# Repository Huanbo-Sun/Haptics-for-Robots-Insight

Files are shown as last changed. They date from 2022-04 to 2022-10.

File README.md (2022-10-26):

# Insight: A Haptic Sensor Powered by Vision and Machine Learning
<p align="right">
  *This is the only official content release regarding the design of Insight.*
</p>

This project shows the principle desing of [Insight](https://www.youtube.com/watch?v=lTAJwcZopAA&t=3s). It is a soft thumb-sized haptic sensor that can enbable robots feel directional force distributions all over a 3D conical surface.

The paper is titled "[A soft thumb-sized vision-based sensor with accurate all-round force perception](https://rdcu.be/cHCl9)", published at [*Nature Machine Intelligence*, 2022](https://rdcu.be/cHCl9). 

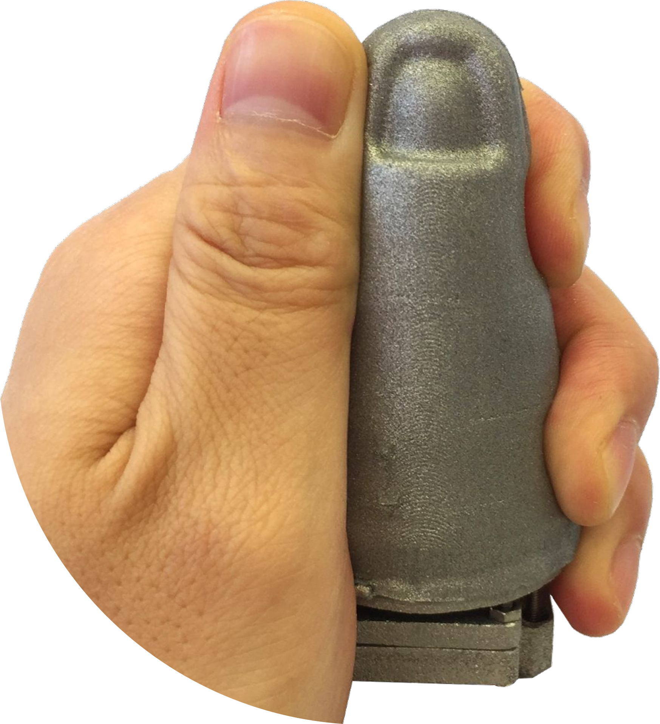
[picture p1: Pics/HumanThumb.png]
<p align="center">
  
This work was done by Huanbo Sun, Katherine J. Kuchenbecker, Georg Martius at the Max Planck Institute for Intelligent Systems.
  
If you make used of our work, please use the citation information [below](#Citation).
  
# Abstract
Vision-based haptic sensors have emerged as a promising approach to robotic touch due to affordable high-resolution cameras and successful computer vision techniques; however, their physical design and the information they provide do not yet meet the requirements of real applications. We present a robust, soft, low-cost, vision-based, thumb-sized three-dimensional haptic sensor named Insight, which continually provides a directional force-distribution map over its entire conical sensing surface. Constructed around an internal monocular camera, the sensor has only a single layer of elastomer over-moulded on a stiff frame to guarantee sensitivity, robustness and soft contact. Furthermore, Insight uniquely combines photometric stereo and structured light using a collimator to detect the three-dimensional deformation of its easily replaceable flexible outer shell. The force information is inferred by a deep neural network that maps images to the spatial distribution of three-dimensional contact force (normal and shear). Insight has an overall spatial resolution of 0.4 mm, a force magnitude accuracy of around 0.03 N and a force direction accuracy of around five degrees over a range of 0.03–2 N for numerous distinct contacts with varying contact area. The presented hardware and software design concepts can be transferred to a wide variety of robot parts.

# Working Mechanism
## Hardware Design
Insight is a vision-based haptic sensor that uses a camera and a structured lighting system to detect external contact happened on a soft hollow elastomer.
  
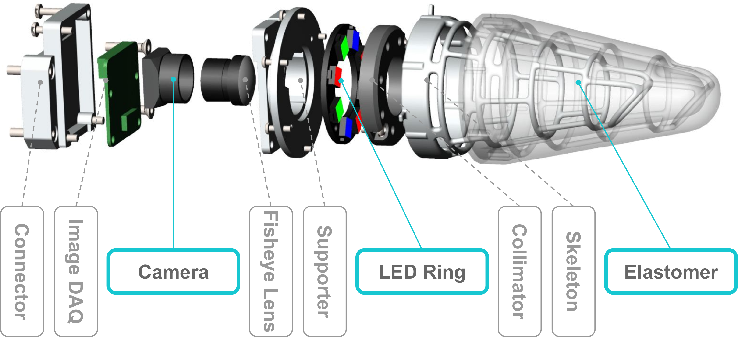
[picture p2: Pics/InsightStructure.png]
<p align="center">
  
## Software Design
Insight constantly records images from inside using a camera. Feeding these images and a reference image into a trained machine learning model makes it possible to estimate the force distribution all over a surface. Each pixel in the force prediction map has three values that indicate the force strength in three directions (x, y, and z). In a force visualization on the right, each point corresponding to each pixel in the force map shows the force distribution of the contact in both normal and shear directions.
  
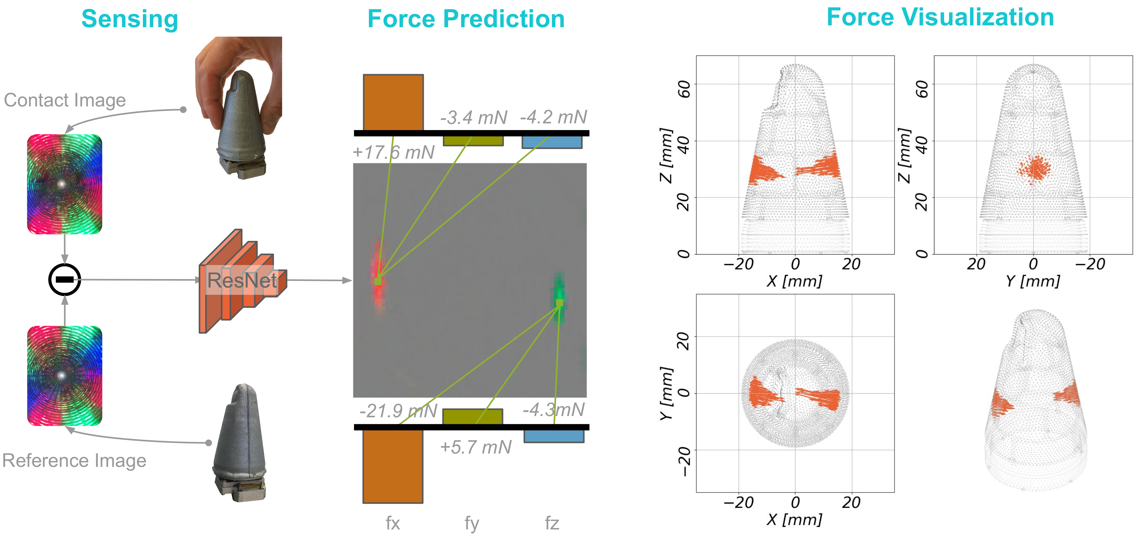
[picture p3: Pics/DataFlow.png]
  <p align="center">
    
# Key Components
Four key design components make Insight work properly: the mechanical design of its shell, the tailored imaging system inside, automatic data collection, and cutting-edge deep learning are used behind the scenes to create a cheap, robust, and high-fidelity device.
     
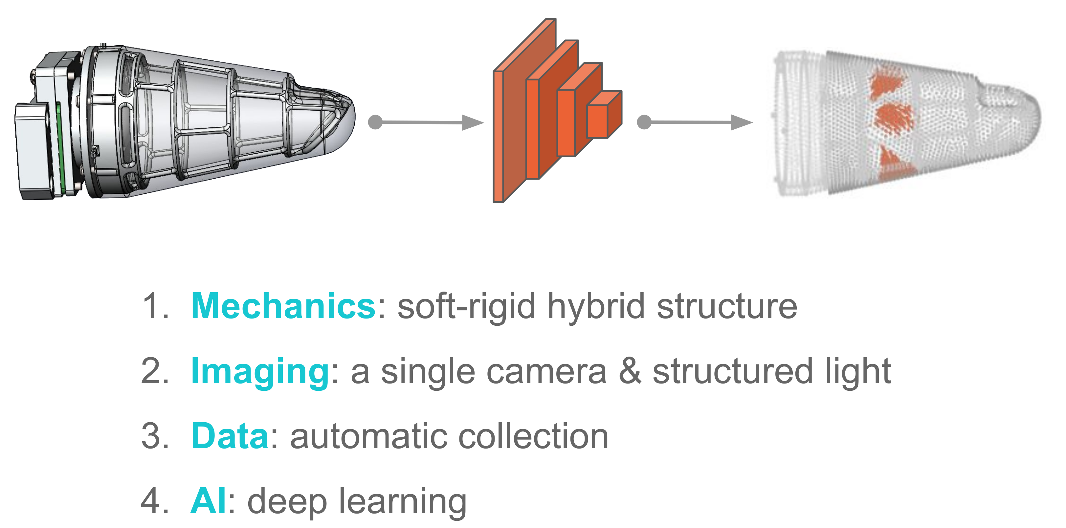
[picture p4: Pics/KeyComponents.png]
  <p align="center">
       
## Mechanics
Our hybrid structure of a soft elastomer shell enclosing a stiff metal skeleton ensures high sensitivity and robustness. The soft elastomer is for detecting light contact with high sensitivity. The metal skeleton is for holding the elastomer’s global shape and sustaining high-impact forces.

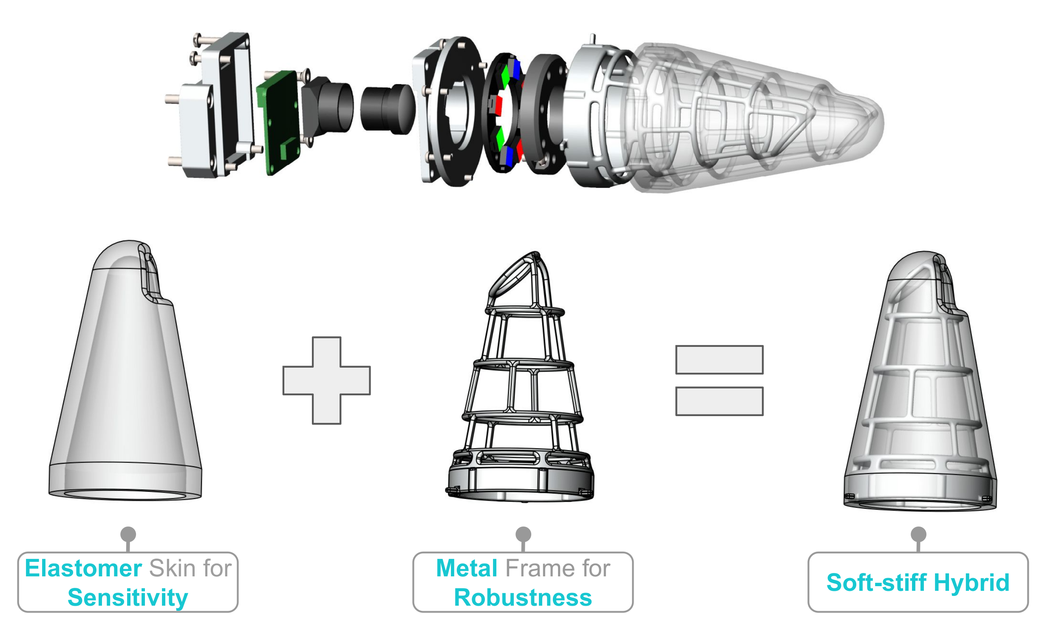
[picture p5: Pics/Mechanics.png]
  <p align="center">

### Elastomer
- 3D Printer: [Formlabs Form 3](https://formlabs.com/eu/3d-printers/form-3/)
- 3D Printing Material: [Tough Resin FLTOTL05](https://formlabs.com/store/tough-2000-resin/). *Note: The material is updated.*
- Mold Design: 
  - [Mold 1](Solidworks/Elastomer_Mold1_In_Fingerprint_NailFlat.SLDPRT)
  - [Mold 2](Solidworks/Elastomer_Mold2_Out1.SLDPRT)
  - [Mold 3](Solidworks/Elastomer_Mold2_Out2.SLDPRT)
- Elastomer Material:
  - [EcoFlex 00-30](https://www.smooth-on.com/products/ecoflex-00-30/)
  - [Aluminum Powder 65 Micrometer, 99% Pure](https://www.amazon.de/Aluminumpulver-Aluminium-Pulver-Alupulver-Zus%C3%A4tze/dp/B06WRTGP2Y)
  - [Aluminum Flake 75 Micrometer](https://www.metallpulver24.de/de/aluminiumpulver-flaky-silber.html)
- [Vacuum Chamber VP1100, 5 Pa](https://www.silikonfabrik.de/vakuumtechnik/komplettsysteme/vakuum-komplettsystem-vks27/vp1200-vakuumkammer-und-pumpe.html). *Note: The Pump is updated.*
       
### Metal Skeleton
- 3D Printer: [ExOne X1 25 Pro](https://www.exone.com/en-US/Resources/News/X1-25PRO)
- 3D Printing Material: [AlSi10Mg-0403 Alluminum Alloy](https://www.shapeways.com/materials/aluminum) *Note: The material is updated.*
- Geometry Design: [Skeleton](Solidworks/Skeleton.SLDPRT)
- Printing Service: [Shapeways](https://www.shapeways.com/)
       
### Connector and Supporter
- 3D Printer: [ExOne X1 25 Pro](https://www.exone.com/en-US/Resources/News/X1-25PRO)
- 3D Printing Material: [AlSi10Mg-0403 Alluminum Alloy](https://www.shapeways.com/materials/aluminum) *Note: The material is updated.*
- Geometry Design: 
  - [Connector](Solidworks/Connector.SLDPRT)
  - [Supportor](Solidworks/Supporter.SLDPRT)
- Printing Service: [Shapeways](https://www.shapeways.com/)
      
## Imaging System
We use a LED ring and a collimator to create structured light. The structured light forms a light cone inside the enclosed volume. Each voxel inside this volume has a specific color code with 3D information. External contact moves the elastomer from one color zone to another. Together with shading effects the camera can detect 3D deformations of the surface from a single 2D image. As shown on the right figure, mimicking human fingerprint, we also add ridges to the surface to help the system recognize the directions of the surface extension.

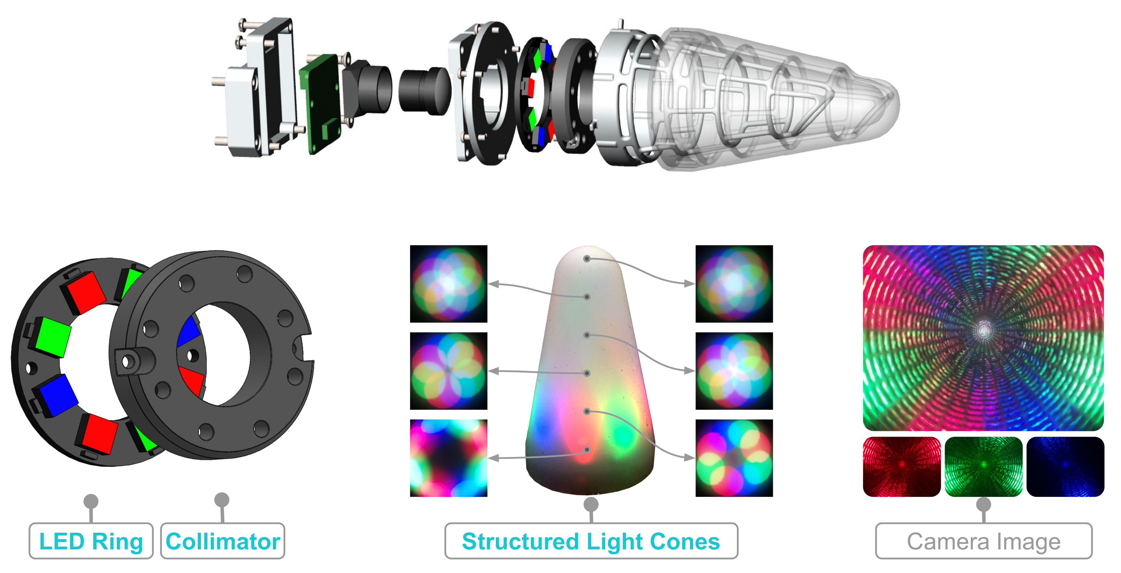
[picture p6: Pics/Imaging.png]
  <p align="center">
    
### Camera
- [Maker Hawk Raspberry Pi Camera Module 8 MP (Raspberry Pi camera V.2.0)](https://www.amazon.co.uk/MakerHawk-Raspberry-Compatible-Supporting-Resolution/dp/B07HL3Q58Z)

### LED Ring
- [Neopixel Ring with eight pieces of WS2812 5050](https://www.amazon.de/gp/product/B019ZL6724/ref=ppx_yo_dt_b_asin_title_o05_s00?ie=UTF8&psc=1)       

### Collimator
- 3D Printer: [Formlabs Form 3](https://formlabs.com/eu/3d-printers/form-3/)
- Material: [Standard Black](https://formlabs.com/de/shop/black-resin/)
- Geometry Design: [Collimator](Solidworks/Collimator.SLDPRT)

### DAQ
- [Raspberry Pi 4 Model B](https://www.raspberrypi.com/products/raspberry-pi-4-model-b/) 
- [Python Code Runs in Raspberry Pi](Code/Python-Rasberry.md)

## Testbed
We design a test bed to stimulate the sensor in a controlled way, with both normal and shear forces, over the entire 3D sensing surface.
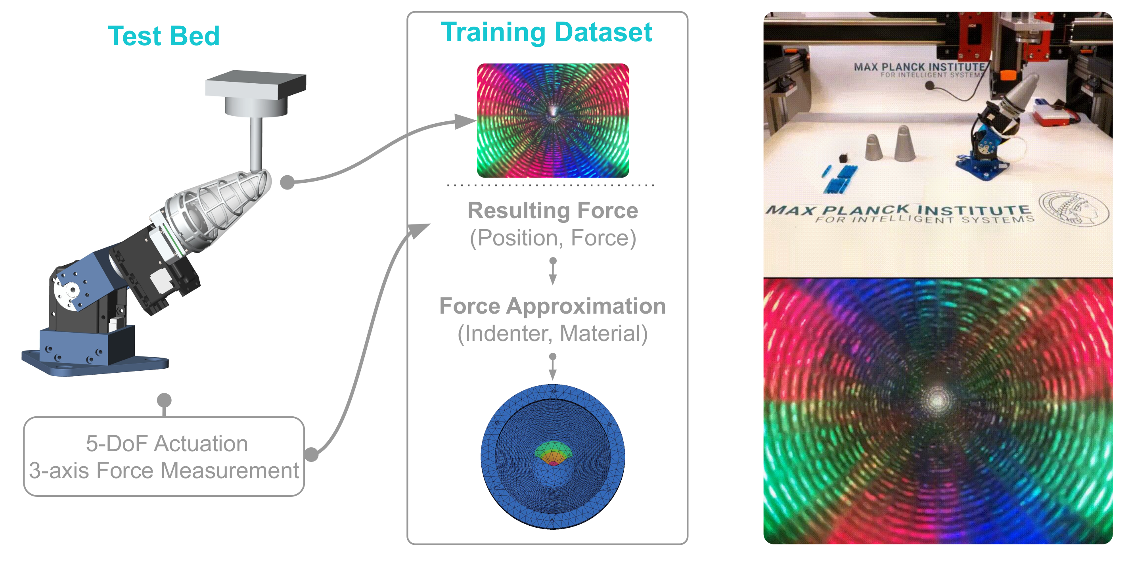
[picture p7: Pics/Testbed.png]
   <p align="center"> 

### Linear Guide for 3 DOF Translation
- [Linear Guide](https://www.barchmotion.com/)
   - [Linear Guide Geometry](Pics/BarchMotionGeometry.png)
   - [Linear Guide Order List](Pics/BarchMotionOrder.png)
- [Power Supplier](https://www.boomaudio.de/mean-well-rsp-320-36-netzteil)
   - [RSp-320-36](https://www.boomaudio.de/mean-well-rsp-320-36-netzteil)
- [Arduino for Testbed](https://store.arduino.cc/products/arduino-micro)
   - [Arduino Micro](https://store.arduino.cc/products/arduino-micro)
   - [Arduino Code](Code/Testbed-Arduino.md)

### Motors for 2 DOF Rotation
- [Dynamixel Mx28-AT](https://emanual.robotis.com/docs/en/dxl/mx/mx-28/)
- [Dynamixel Mx64-AT](https://emanual.robotis.com/docs/en/dxl/mx/mx-64/)
- [Connector Mx64-AT-Testbed-Base](Solidworks/Mx64-AT-Testbed-Base.SLDPRT)
- [Connector Mx28-AT-Mx64-AT](Solidworks/Mx28-AT-Mx64-AT.SLDPRT)

### Force/Torque Sensor
- [ATI-MINI 40](https://www.ati-ia.com/products/ft/ft_models.aspx?id=mini40)
- [DAQ](https://www.ni.com/de-de/support/model.usb-6210.html)
       
# Software
## [Data Collection](Code/00_Experiment.ipynb)
### Communication
### Coordinate Transfer
### Data Collection
## Data Processing
### Direct Single Contact Prediction
### Force Map Predcition
### Mapping/Visualization
       
# Citation
Please use the following citation if you make use of our work:
## BibTex
``` citation
@article{Insight,
  title = {A soft thumb-sized vision-based sensor with accurate all-round force perception},
  author = {Sun, Huanbo and Kuchenbecker, Katherine J. and Martius, Georg},
  journal = {Nature Machine Intelligence},
  volume = {4},
  organization = {Max Planck Institute for Intelligent Systems},
  month = feb,
  year = {2022},
  doi = {10.1038/s42256-021-00439-3},
  url = {https://rdcu.be/cHCl9},
  month_numeric = {2}
  } 
```
### RIS
``` citation
TY  - JOUR
AU  - Sun, Huanbo
AU  - Kuchenbecker, Katherine J.
AU  - Martius, Georg
PY  - 2022
DA  - 2022/02/01
TI  - A soft thumb-sized vision-based sensor with accurate all-round force perception
JO  - Nature Machine Intelligence
SP  - 135
EP  - 145
VL  - 4
IS  - 2
SN  - 2522-5839
UR  - https://doi.org/10.1038/s42256-021-00439-3
DO  - 10.1038/s42256-021-00439-3
ID  - Sun2022   
```

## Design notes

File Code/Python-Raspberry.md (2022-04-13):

```
# Packages
## Neopixel
import board
from fractions import Fraction
import neopixel
## Picamera
import picamera
from picamera import PiCamera, Color
from picamera.array import PiRGBArray
## Communication
import socket
import io
import struct
import pickle
## Processing
import numpy as np
import math
import time

# Camera
def imaging():
    camera = PiCamera(resolution=(1640,1232),framerate=40)
    camera.iso = 100
    time.sleep(2)
    camera.shutter_speed = camera.exposure_speed
    camera.exposure_mode = 'off'
    camera.awb_mode = 'off'
    camera.awb_gains = (Fraction(387,256), Fraction(477,256))
    return camera

# Light
def lightning():
    pixels_M = neopixel.NeoPixel(board.D18,8,auto_write=True)
    pr = 1.0#1.0
    pg = 1.0#0.9
    pb = 0.5
    b0 = int(255.0*pr)
    b1 = int(255.0*pg)
    b2 = int(255.0*pb)
    b3 = int(255.0*pr)
    b4 = int(255.0*pg)
    b5 = int(255.0*pr)
    b6 = int(255.0*pb)
    b7 = int(255.0*pg)
    pixels_M[0]=(b0,0,0)
    pixels_M[1]=(0,b1,0)
    pixels_M[2]=(0,0,b2)
    pixels_M[3]=(b3,0,0)
    pixels_M[4]=(0,b4,0)
    pixels_M[5]=(b5,0,0)
    pixels_M[6]=(0,0,b6)
    pixels_M[7]=(0,b7,0)
    pixels_M.write()
    time.sleep(0.025)

# Main
client_socket = socket.socket()
client_socket.connect(('--.--.--.--', ----))
a = client_socket.recv(256)
print(a)
connection = client_socket.makefile('wb')

lightning()
camera = imaging()
camera.start_preview()
time.sleep(0.1)

try:
    while True:
        a = client_socket.recv(256)
        stream = io.BytesIO()
        camera.capture(stream,'jpeg',use_video_port=True)
        connection.write(struct.pack('<L',stream.tell()))
        connection.flush()
        stream.seek(0)
        connection.write(stream.read())
        stream.seek(0)
        stream.truncate()
finally:
    time.sleep(1)
    connection.close()
    client_socket.close()
```

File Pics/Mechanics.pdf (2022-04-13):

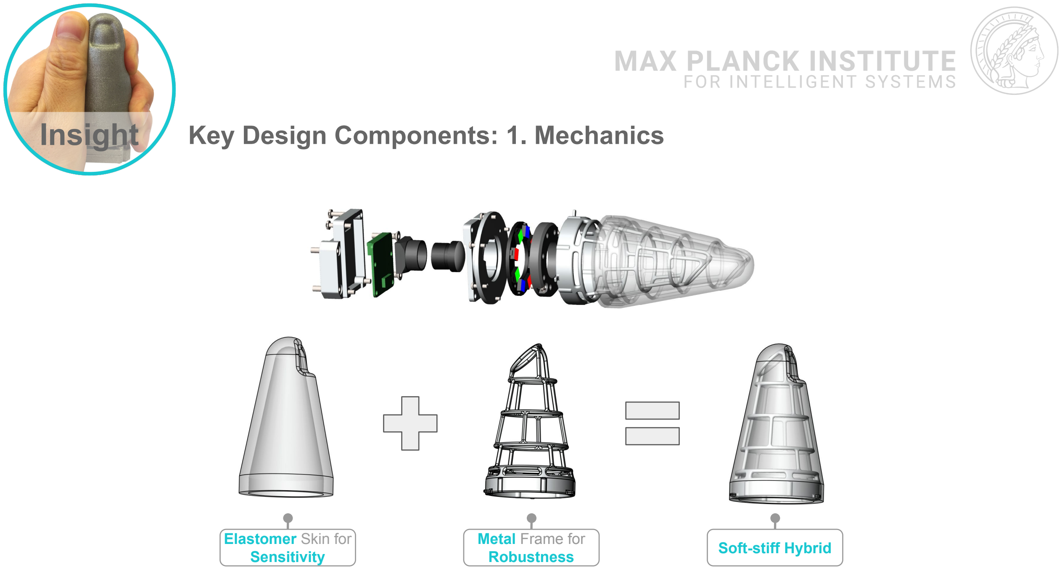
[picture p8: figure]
Key Design Components: 1. Mechanics; Elastomer Skin for Sensitivity; Metal Frame for; Robustness; Soft-stiff Hybrid

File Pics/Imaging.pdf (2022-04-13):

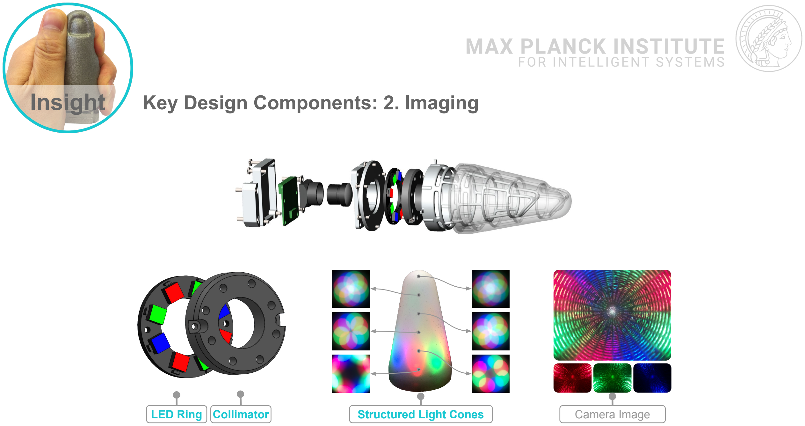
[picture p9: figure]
Key Design Components: 2. Imaging; LED Ring Collimator; Structured Light Cones; Camera Image

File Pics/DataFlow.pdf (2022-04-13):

Sensing | Force Prediction | Force Visualization

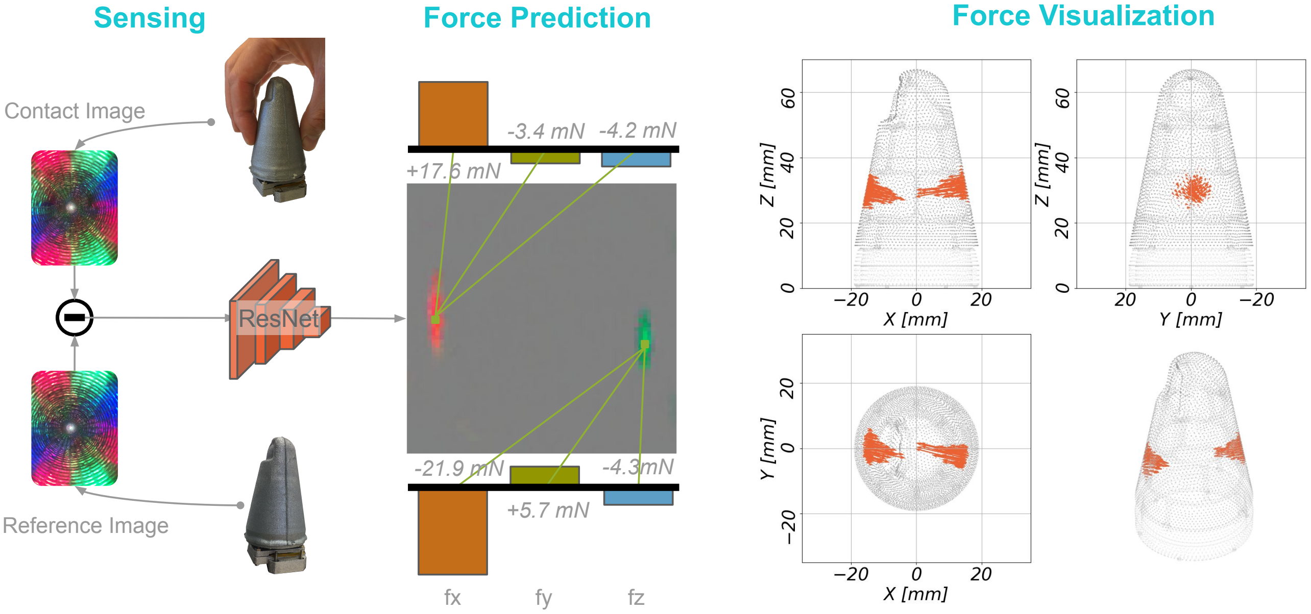
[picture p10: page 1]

+17.6 mN

-3.4 mN -4.2 mN

-21.9 mN

fx | fy | fz
| +5.7 mN | -4.3mN

Contact Image

Reference Image

ResNet

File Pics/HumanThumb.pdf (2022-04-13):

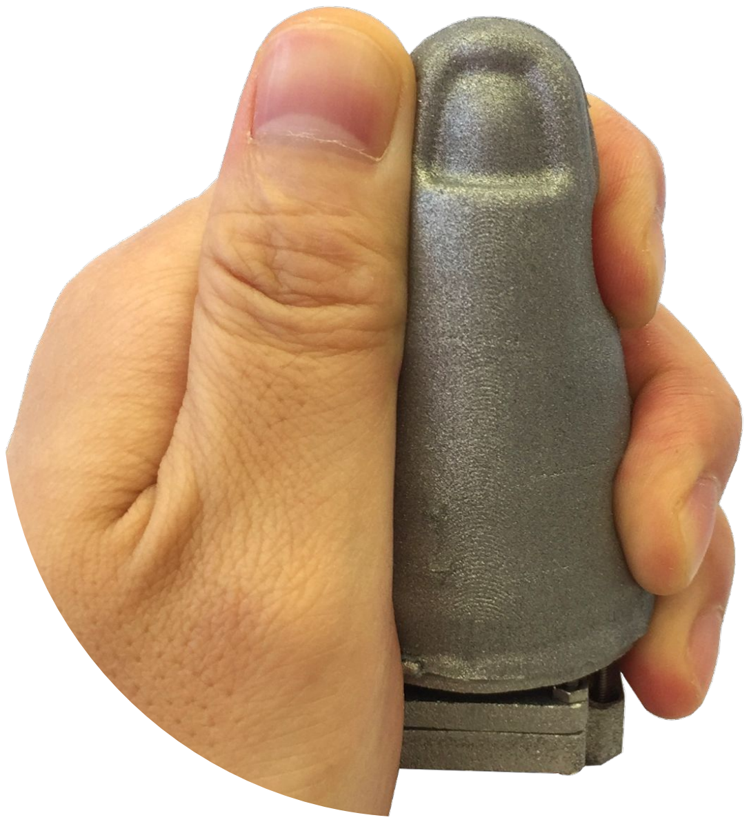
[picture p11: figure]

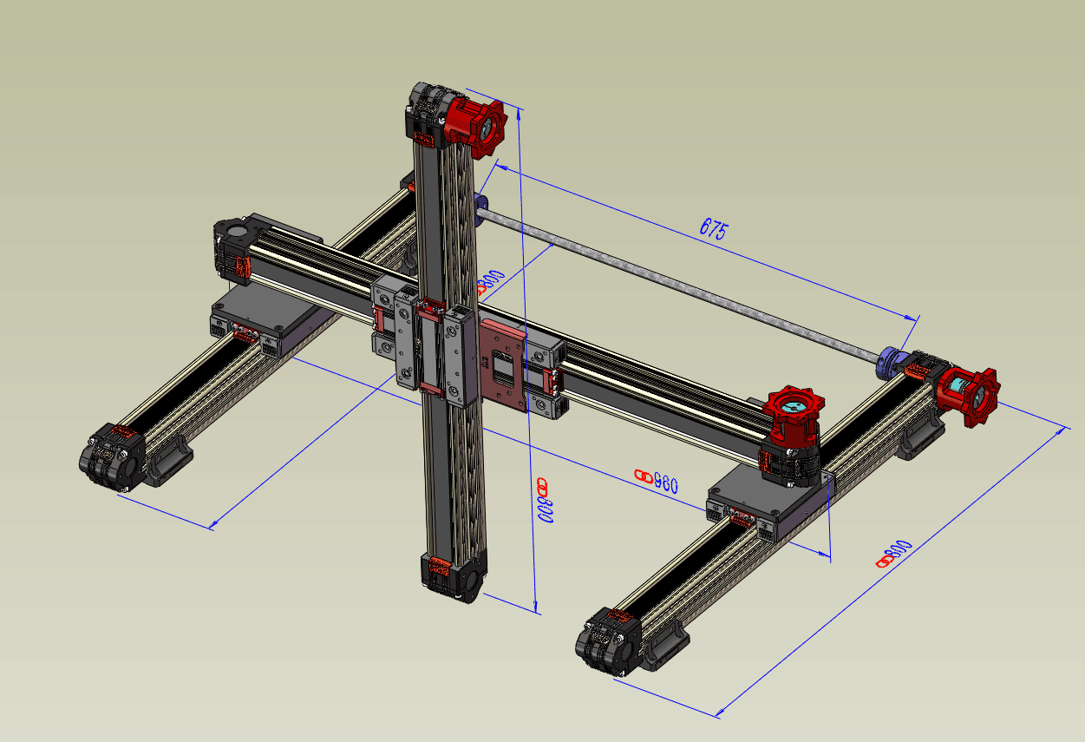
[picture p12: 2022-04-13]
Pics/BarchMotionGeometry.png

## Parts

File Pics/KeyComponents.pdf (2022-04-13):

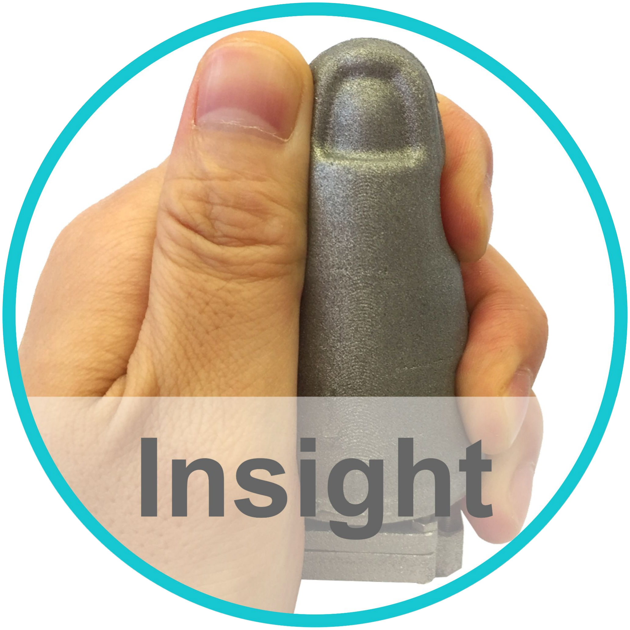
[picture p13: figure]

Key Design Components

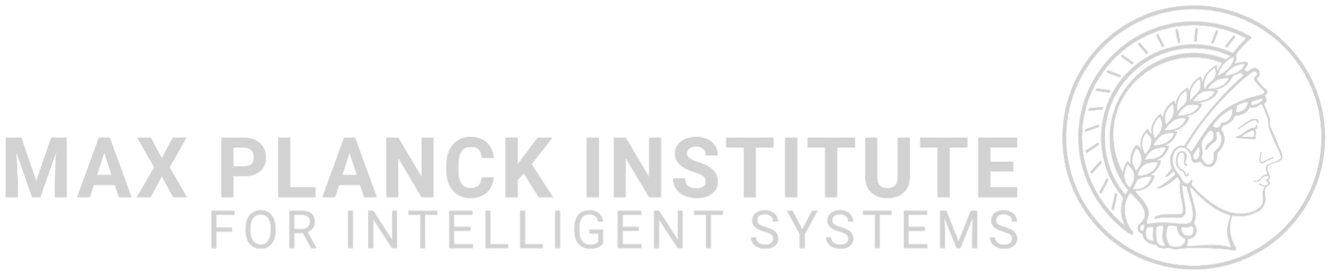
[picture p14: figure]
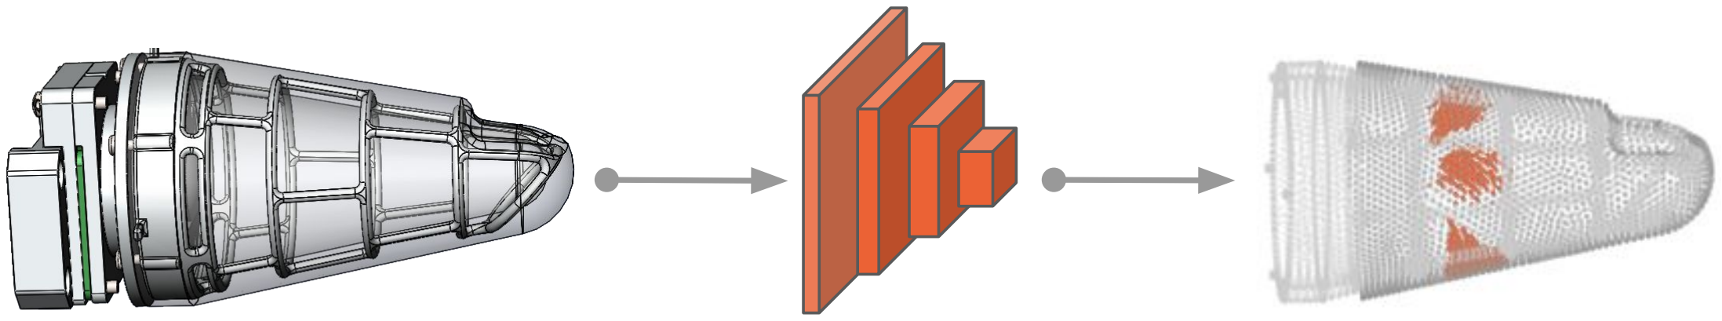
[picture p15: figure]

1. Mechanics: soft-rigid hybrid structure
2. Imaging: a single camera & structured light
3. Data: automatic collection
4. AI: deep learning

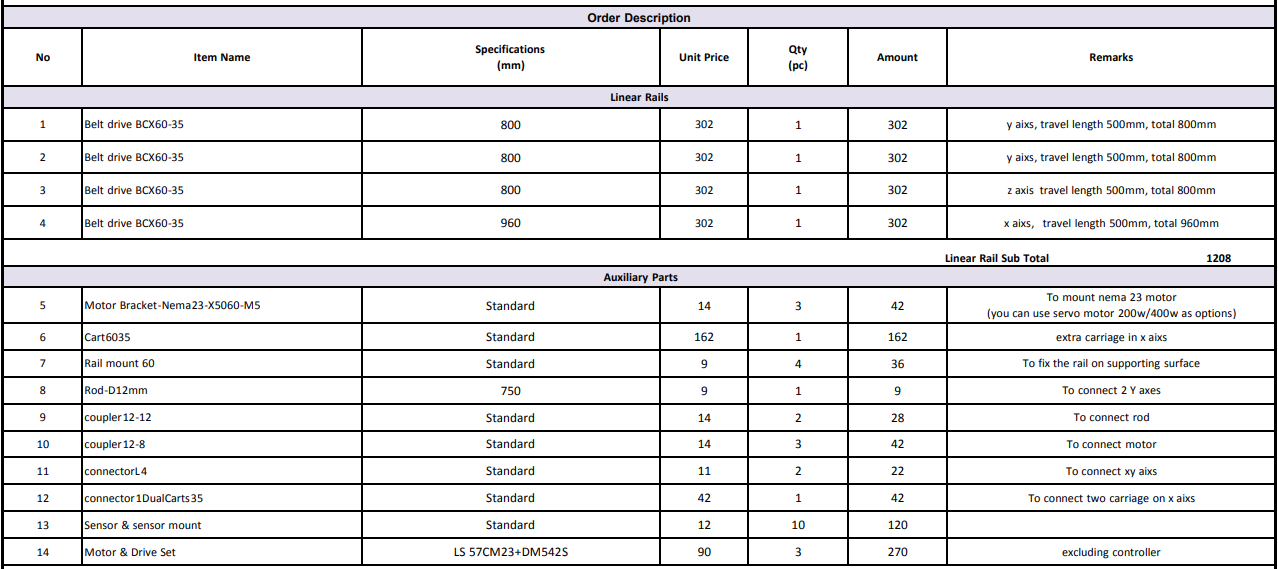
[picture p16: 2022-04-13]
Pics/BarchMotionOrder.png

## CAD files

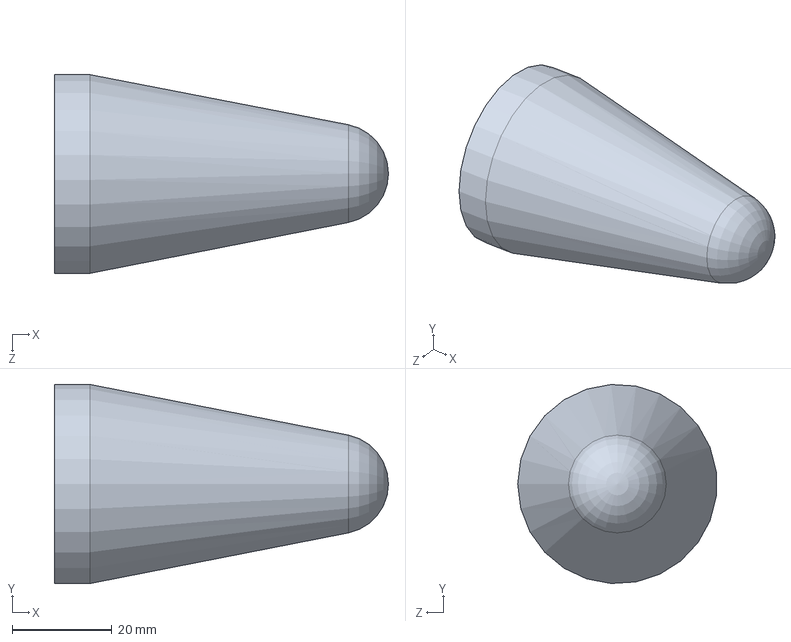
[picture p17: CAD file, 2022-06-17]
Solidworks/Smooth_Shell.SLDPRT
67.0 x 39.9 x 39.8 mm

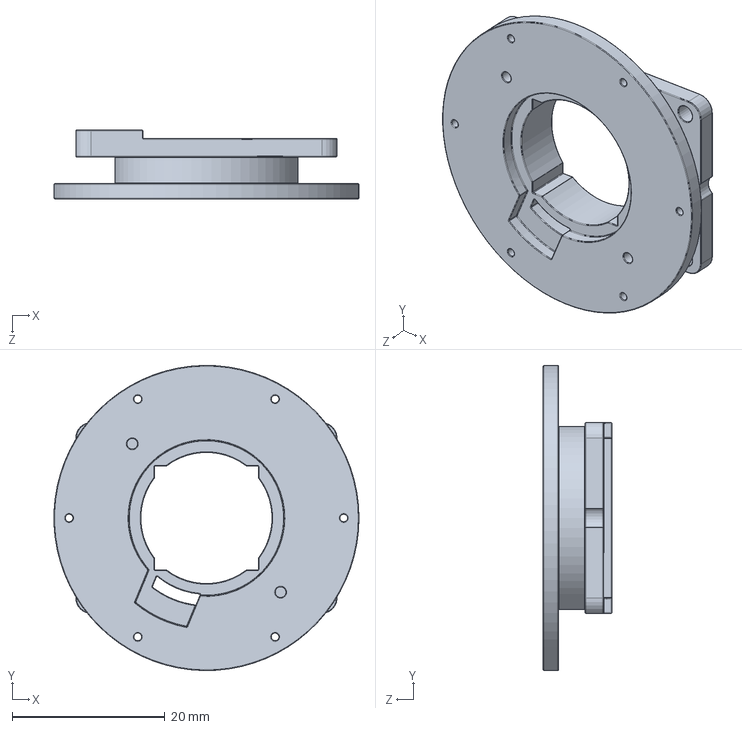
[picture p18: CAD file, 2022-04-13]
Solidworks/Supporter.SLDPRT
40.0 x 40.0 x 9.00 mm

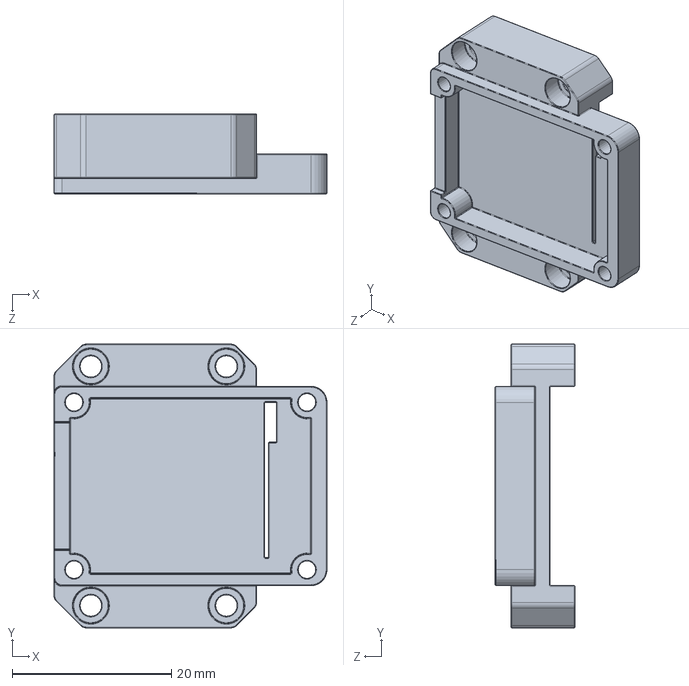
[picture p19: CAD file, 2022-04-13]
Solidworks/Connector.SLDPRT
34.2 x 35.6 x 10.0 mm

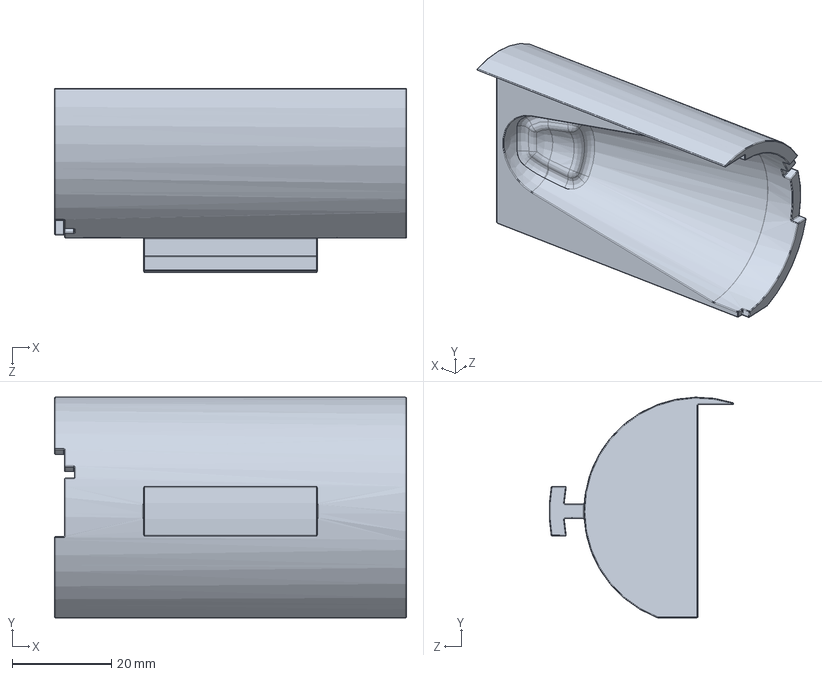
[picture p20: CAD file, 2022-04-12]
Solidworks/Elastomer_Mold2_Out1.SLDPRT
71.0 x 44.5 x 37.2 mm

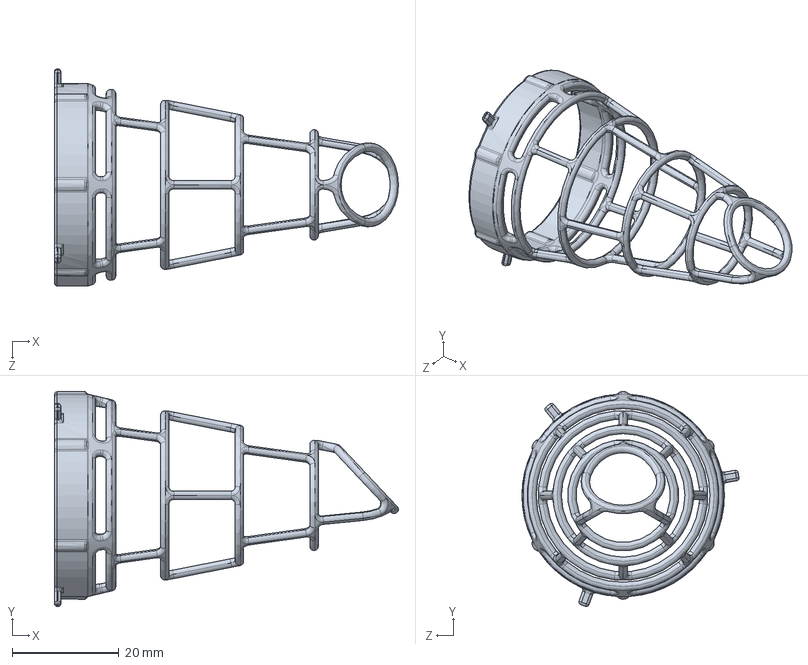
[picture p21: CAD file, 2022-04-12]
Solidworks/Skeleton.SLDPRT
64.5 x 40.4 x 40.8 mm

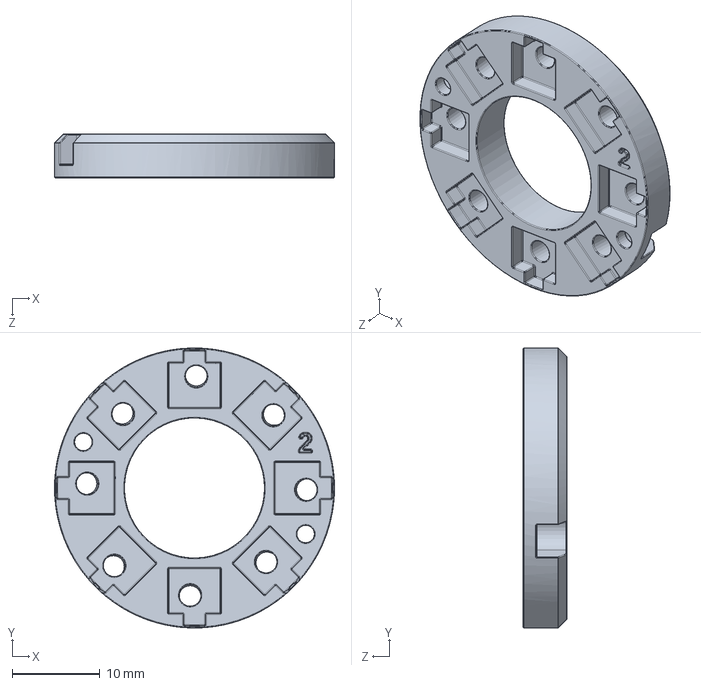
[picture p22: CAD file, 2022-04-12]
Solidworks/Collimator.SLDPRT
32.0 x 32.0 x 5.00 mm

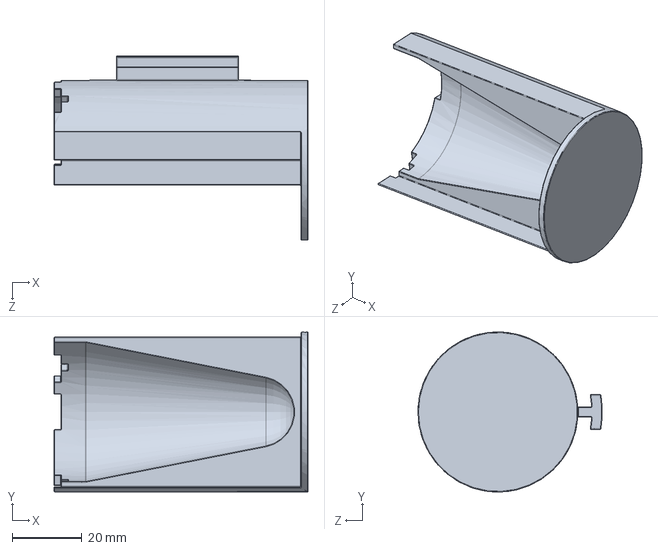
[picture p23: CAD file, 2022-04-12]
Solidworks/Elastomer_Mold3_Out2.SLDPRT
73.0 x 46.0 x 53.0 mm

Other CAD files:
Solidworks/Smooth_Shell_FingerNail.SLDPRT

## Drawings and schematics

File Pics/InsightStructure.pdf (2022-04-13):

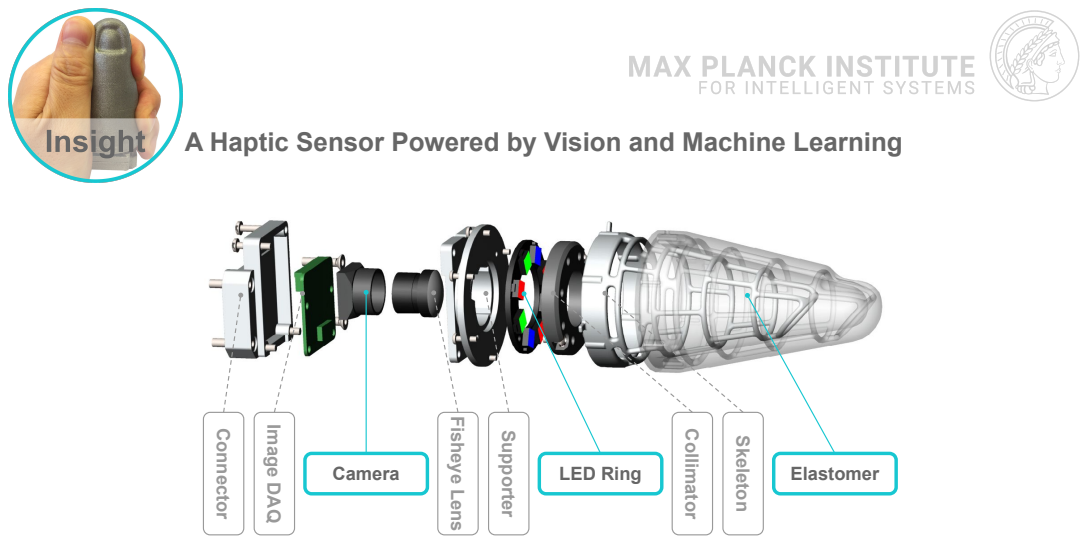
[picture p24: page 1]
A Haptic Sensor Powered by Vision and Machine Learning Connector; Image DAQ; Camera; Fisheye Lens; Supporter; LED Ring; Collimator; Skeleton; Elastomer

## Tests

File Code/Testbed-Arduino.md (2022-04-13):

```
// Motor Setting
byte M_LED = 2;
byte M1_dirPin = 11;
byte M2_dirPin = 10;
byte M3_dirPin = 9;
byte M1_stepPin = 6;
byte M2_stepPin = 5;
byte M3_stepPin = 3;
byte Motor_ENB = 13;
// Switch Sensor Setting
int S1 = A0;
int S2 = A1;
int S3 = A2;
int S4 = A3;
int S5 = A4;
int S6 = A5;
int S[6] = {0, 0, 0, 0, 0, 0};
float s[6] = {0, 0, 0, 0, 0, 0};
// Action Requirement
float A[4] = {0.0, 0.0, 0.0, 0.0};
// Position
int P[3] = {0, 0, 0};
int Pu[3] = {0, 0, 0};
// Distance Counting
float Step_Rotation = 10000.0;
int M1_Steps = 0;
int M2_Steps = 0;
int M3_Steps = 0;
// Overshoot Flag
int Flag = 0;

void SensorValue(int S[])
{
  S[0] = analogRead(S1);
  S[1] = analogRead(S2);
  S[2] = analogRead(S3);
  S[3] = analogRead(S4);
  S[4] = analogRead(S5);
  S[5] = analogRead(S6);
}

void sensorvalue(float s[])
{
  SensorValue(S);
  float a = 0.3;
  s[0] = a*s[0] + (1-a)*S[0];
  s[1] = a*s[1] + (1-a)*S[1];
  s[2] = a*s[2] + (1-a)*S[2];
  s[3] = a*s[3] + (1-a)*S[3];
  s[4] = a*s[4] + (1-a)*S[4];
  s[5] = a*s[5] + (1-a)*S[5];
  }

void CurrentPosition(int P[])
{
  P[0] = M1_Steps;
  P[1] = M2_Steps;
  P[2] = M3_Steps;
}

void ActionValue(float A[])
{
  while(!Serial.available()) {}
  String readString,str[4];
  int count=0;
  while (Serial.available())
  {
    if (Serial.available() >0)
    { 
      char c = Serial.read();
      readString += c;
      str[count] +=c;
      if(c==','){count+=1;}
      if(c=='\n'){}
    }
  }
  A[0] = str[0].toFloat();
  A[1] = str[1].toFloat();
  A[2] = str[2].toFloat();
  A[3] = str[3].toFloat();
}

void UpdatePosition(int Pu[],int Flag)
{
  CurrentPosition(P);
  if(A[1]>300.0 or A[2]>480.0 or A[3]>80.0){Flag=1;} else {Flag=0;}
  int m1_step = int(A[1]/110.0*Step_Rotation);
  int m2_step = int(A[2]/110.0*Step_Rotation);
  int m3_step = int(A[3]/110.0*Step_Rotation);
  Pu[0] = m1_step-P[0];
  Pu[1] = m2_step-P[1];
  Pu[2] = m3_step-P[2];
}

void GotoPosition()
{
  UpdatePosition(Pu,Flag);
  if(Flag==0){
    int M1_sign,M2_sign,M3_sign;
    if(Pu[0]<0){digitalWrite(M1_dirPin, HIGH);M1_sign =-1;} else {digitalWrite(M1_dirPin, LOW);M1_sign=1;}
    if(Pu[1]<0){digitalWrite(M2_dirPin, LOW);M2_sign=-1;}   else {digitalWrite(M2_dirPin, HIGH);M2_sign=1;}
    if(Pu[2]<0){digitalWrite(M3_dirPin, HIGH);M3_sign=-1;}  else {digitalWrite(M3_dirPin, LOW);M3_sign=1;}
    int P_max = max(max(abs(Pu[0]),abs(Pu[1])),abs(Pu[2]));
    digitalWrite(M_LED, HIGH);
    for(int n=0;n<(P_max);n++)
    { 
      SensorValue(S);
      if(n<abs(Pu[0])){digitalWrite(M1_stepPin, HIGH);digitalWrite(M1_stepPin, LOW);M1_Steps += M1_sign; delay(0.000002);}
      if(n<abs(Pu[1])){digitalWrite(M2_stepPin, HIGH);digitalWrite(M2_stepPin, LOW);M2_Steps += M2_sign; delay(0.000002);}
      if(n<abs(Pu[2])){digitalWrite(M3_stepPin, HIGH);digitalWrite(M3_stepPin, LOW);M3_Steps += M3_sign; delay(0.000002);}
    }
    digitalWrite(M_LED, LOW);
  }
}

void SendPosition()
{
  float x_p,y_p,z_p;
  CurrentPosition(P);
  x_p = P[0]*110.0/Step_Rotation;
  y_p = P[1]*110.0/Step_Rotation;
  z_p = P[2]*110.0/Step_Rotation;
  Serial.print(3.0);
  Serial.print(" ");
  Serial.print(x_p);
  Serial.print(" ");
  Serial.print(y_p);
  Serial.print(" ");
  Serial.print(z_p);
  Serial.println(" ");
}

void action_in_arduino()
{
  ActionValue(A);
  if (A[0]==0.0){initialization();}
  if (A[0]==1.0){GotoPosition();}
  if (A[0]==2.0){SendPosition();}
}

void initialization()
{ 
  digitalWrite(M1_dirPin, HIGH);
  digitalWrite(M2_dirPin, LOW);
  digitalWrite(M3_dirPin, HIGH);
  digitalWrite(M_LED,HIGH);
  while(1)
  {
    sensorvalue(s);
    if(s[0]<400){digitalWrite(M1_stepPin, HIGH);digitalWrite(M1_stepPin, LOW);}
    if(s[2]<400){digitalWrite(M2_stepPin, HIGH);digitalWrite(M2_stepPin, LOW);}
    if(s[4]<400){digitalWrite(M3_stepPin, HIGH);digitalWrite(M3_stepPin, LOW);}
    if(s[0]>400 && s[2]>400 && s[4]>400){break;}
    delay(0.00001);
  }
  digitalWrite(M_LED,LOW);
  delay(1);
  
  digitalWrite(M1_dirPin, LOW);
  digitalWrite(M2_dirPin, HIGH);
  digitalWrite(M3_dirPin, LOW);
  digitalWrite(M_LED,HIGH);
  while(1)
  {
    sensorvalue(s);
    if(s[0]>400){digitalWrite(M1_stepPin, HIGH);digitalWrite(M1_stepPin, LOW);}
    if(s[2]>400){digitalWrite(M2_stepPin, HIGH);digitalWrite(M2_stepPin, LOW);}
    if(s[4]>400){digitalWrite(M3_stepPin, HIGH);digitalWrite(M3_stepPin, LOW);}
    if(s[0]<400 && s[2]<400 && s[4]<400){break;}
    delay(0.00001);
  }
  digitalWrite(M_LED,LOW);
  delay(1);

  digitalWrite(M1_dirPin, HIGH);
  digitalWrite(M2_dirPin, LOW);
  digitalWrite(M3_dirPin, HIGH);
  digitalWrite(M_LED,HIGH);
  while(1)
  { sensorvalue(s);
    if(s[0]<400){digitalWrite(M1_stepPin, HIGH);digitalWrite(M1_stepPin, LOW);}
    if(s[2]<400){digitalWrite(M2_stepPin, HIGH);digitalWrite(M2_stepPin, LOW);}
    if(s[4]<400){digitalWrite(M3_stepPin, HIGH);digitalWrite(M3_stepPin, LOW);}
    if(s[0]>400 && s[2]>400 && s[4]>400){break;}
    delay(0.000001);
  }
  digitalWrite(M_LED,LOW);
  M1_Steps = 0;
  M2_Steps = 0;
  M3_Steps = 0;
  delay(1);
}

void setup() {
  Serial.begin(115200);
  
  pinMode(M_LED,OUTPUT);
  pinMode(M1_dirPin, OUTPUT);
  pinMode(M2_dirPin, OUTPUT);
  pinMode(M3_dirPin, OUTPUT);
  pinMode(M1_stepPin, OUTPUT);
  pinMode(M2_stepPin, OUTPUT);
  pinMode(M3_stepPin, OUTPUT);
  pinMode(Motor_ENB,OUTPUT);
  
  digitalWrite(Motor_ENB, LOW);
  delay(10);
}

void loop() {
  action_in_arduino();
}
```

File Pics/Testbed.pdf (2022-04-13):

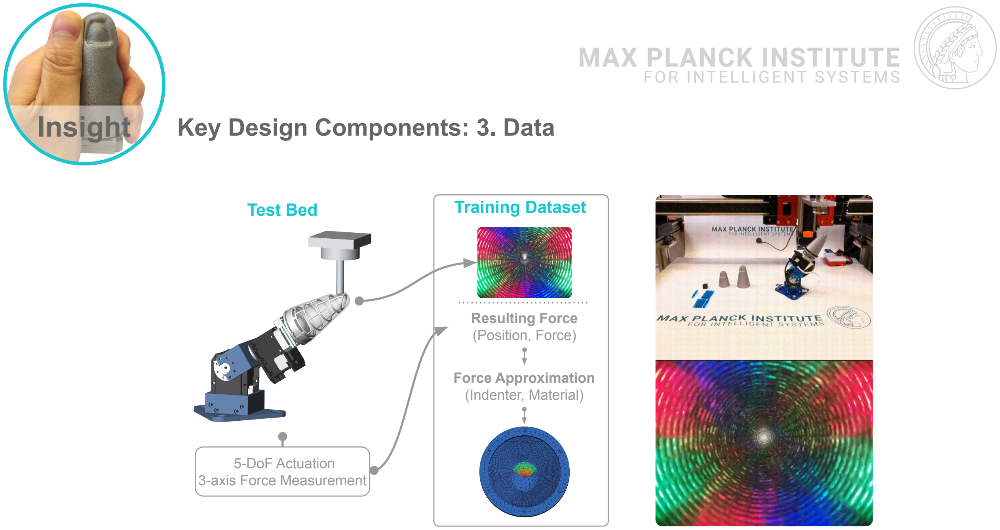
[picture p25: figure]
Key Design Components: 3. Data; Training Dataset; Resulting Force (Position, Force); Force Approximation (Indenter, Material); Test Bed; 5-DoF Actuation 3-axis Force Measurement
